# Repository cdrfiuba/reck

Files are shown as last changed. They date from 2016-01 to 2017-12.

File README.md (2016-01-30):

# reck
R.E.C.K

Robot Eyes Caterpillar Kinect

Robot autónomo con capacidad para filmar, seguir un objeto, entre otras caracteristicas.

Caracteristicas generales: altura entre 1 y 1,5 metros; sistema de desplazamiento con orugas; cuenta con una Raspberry Pi; "cabeza" formada por una Kinect; "cuerpo" acoplado a la estructura de un gabinete, lugar donde se van a colocar las placas de conexión; la estructura va a estar conectada a través de caños; la proteccion de las placas va a ser con placa de acrílilco.

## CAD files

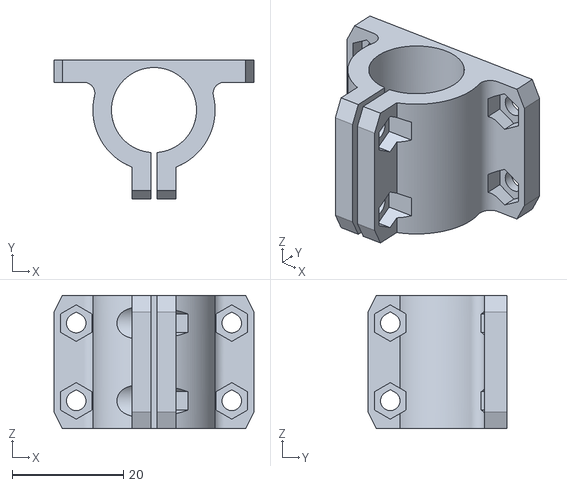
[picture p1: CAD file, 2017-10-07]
3dmodels/lm8uu_holder_v2.stl
36.0 x 25.0 x 24.0

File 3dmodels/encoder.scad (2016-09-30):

$fn=250;
module motor(){
cylinder(h=2.5,d=10);
cylinder(h=6,d=2);
translate([0,0,-20])cylinder(h=20,d=28);

translate([23/2.0,-2,0])cube([0.5,4,7]);
translate([-23/2.0-0.5,-2,0])cube([0.5,4,7]);
}

module encoder(N){
  L = 360/(2*N);
  difference(){
    union(){
      translate([0,0,2.6])cylinder(h=1.2  , d=22);
      translate([0,0,2.6])cylinder(h=3.4, d= 5);
    }
    translate([0,0,2.5])
    difference() {
      union(){
        for(i=[0:(N-1)])
        rotate([0,0,i*360/N])
        polyhedron( 
          points = [ [0, 0, 0], [15, 0, 0], [15*cos(L),15*sin(L),0],[0, 0, 2], [15, 0, 2], [15*cos(L),15*sin(L),2]], 
          faces = [ [0, 1, 4, 3], [1,2,5,4],[2,0,3,5],[0,2,1],[3,4,5] ], 
          convexity = 10);
      }
      cylinder(h=4.5, d=6);
    }
    translate([0,0,2])cylinder(h=5, d=2.6);
  }
}

module pcb() {
  difference(){
    translate([0,0,4])cylinder(h=1.8, d=28);
    translate([23/2.0-0.15,-2.15,5])cube([0.8,4.3,7]);
    translate([-23/2.0-0.65,-2.15,5])cube([0.8,4.3,7]);
    translate([0,0,2])cylinder(h=5, d=6);
    rotate([0,0,45])translate([3.5,-2.15,3.5]) cube([7.3,4.3,3]);
    rotate([0,0,135])translate([3.5,-2.15,3.5]) cube([7.3,4.3,3]);
    
  }
}

//motor();
encoder(3);
//pcb();

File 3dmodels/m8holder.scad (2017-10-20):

import("lm8uu_holder_v2.stl");
translate([-4,2.5,0])cube([8,2.5,2]);

difference(){
  cylinder(h=24,r=8);
  cylinder(h=24.1,r=4.15,$fn=60);
  translate([0.5,0,0]) rotate([0,0,180])cube([1,20,24]);
}

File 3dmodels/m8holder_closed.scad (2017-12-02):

import("lm8uu_holder_v2.stl");

difference() {
  cylinder(h=1,d=18);
  cylinder(h=1,d=9);
  translate([-0.5,-20,0]) cube([1,20,2]);
}

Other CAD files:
3dmodels/plantilla_madera.scad
3dmodels/sprockets.scad
3dmodels/sprockets_reck.scad

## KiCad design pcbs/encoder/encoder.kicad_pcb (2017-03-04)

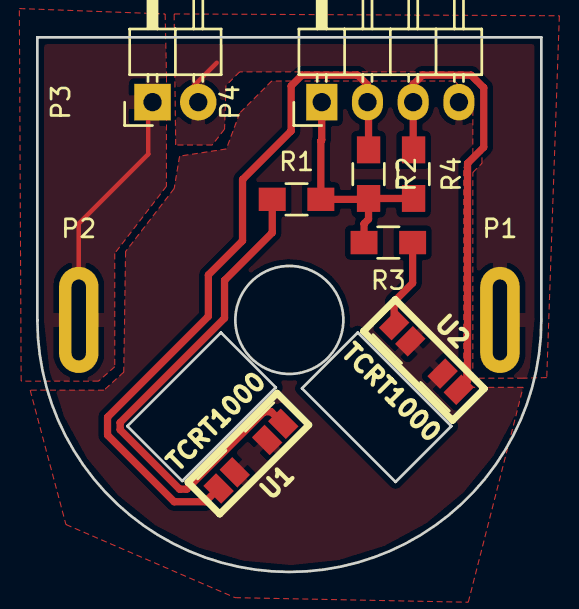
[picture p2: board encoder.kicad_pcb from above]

Board: 2 copper layers, 28.0 x 29.7 mm, 10 parts (0 on the bottom side), 8 nets.

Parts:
P1: M1; SolderWirePad_single_2-5mmDrill
P2: M2; SolderWirePad_single_2-5mmDrill
P3: Motor; Pin_Header_Angled_1x02
P4: CONN_01X04; Pin_Header_Angled_1x04
R1, R2: 180; R_0805_HandSoldering
R3, R4: 33k; R_0805_HandSoldering
U1: TCRT1000; tcrt1000-smd
U2: TCRT1000

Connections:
+5V: P4.1, R1.2, R2.2, R3.2, R4.2
/S1: P4.2, R2.1, U1.4
/S2: P4.3, R4.1, U2.4
GND: P4.4, U1.2, U1.3, U2.2, U2.3
unnamed: P1.1, P3.2
unnamed: P2.1, P3.1
unnamed: R1.1, U1.1
unnamed: R3.1, U2.1

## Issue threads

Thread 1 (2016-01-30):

Actualizar readme

yagui, 2016-01-30:
poner una descripción del robot

julimarasco, 2016-01-30:
Verificar si eso es lo que va en el Readme.
No tengo idea que poner ahí.

yagui, 2016-02-02:
Esta bien, era una primera descripción del robot la cual está bien

Closed 2016-02-02.

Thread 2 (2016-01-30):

subir foto

yagui, 2016-01-30:
edita la wiki y agrega la foto

julimarasco, 2016-01-30:
No se como hacerlo!  :-1:
Lo google pero no lo entendí.

yagui, 2016-02-02:
descargue el repo de la wiki, agregué la foto al repo en mi compu, subi los cambios, y luego edite de vuelta la wiki

Closed 2016-02-02.

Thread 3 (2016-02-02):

armar mail de introduccion

yagui, 2016-02-02:
Armar un mail contando la idea general para atraer gente que quiera trabajar en el proyecto.
Comentar que por un lado hay que armar la estructura, así que hay trabajo para mecánicos y no mecánicos que les guste la parte estructural.
Hay que armar toda la electrónica, desde sensores, control de motores, distribución de energía, etc.
Estética, interacción con el humano. Y sobre software/firmware, estaremos trabajando con ROS a sugerencia de Ernesto.

yagui, 2016-02-02:
@ernestmc

Closed 2016-02-03.

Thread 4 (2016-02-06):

Comprar tarjeta micro SD para rPI 2

sebasgm, 2016-02-06:
Para poder empezar a utilizar la Raspberry PI 2 necesitamos una micro SD

Monty1991, 2016-02-06:
Tengo una Sandisk de 32 gb sin usar, sirve?

sebasgm, 2016-02-06:
Sirve hasta que podamos comprar una. Si querés traela y ni bien tengamos una nueva te la podés llevar.

Monty1991, 2016-02-06:
Dale. ¿Cuándo empiezan a reunirse (en el club, supongo)?

yagui, 2016-07-22:
Juli ya compró la SD

Closed 2016-07-22.

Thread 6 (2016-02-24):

Interfaz humana

ernestmc, 2016-02-24:
Ideas para darle al robot una interfaz más natural y amistosa con las personas, que simule rasgos humanos. Algo similar a [ésta](http://spectrum.ieee.org/automaton/robotics/industrial-robots/sawyer-rethink-robotics-new-robot).

* Usar una tablet Android para dibujar la cara. Se podría usar la propia cámara de la tablet para hacer reconocimiento facial del interlocutor y de esta forma interpretar ciertas expresiones y emociones. Mediante [Rosjava](http://wiki.ros.org/rosjava) y un enlace wifi se puede conectar con el resto del sistema del robot.

* Usando [Jasper](https://jasperproject.github.io/) se puede hacer reconocimiento de voz para interpretar comandos. Existen módulos para usar en español.

* Usar algún sintetizador de voz para emitir respuestas vocales (investigar cuál, si se puede usar en español).

Monty1991, 2016-02-25:
En cuanto a sintetizadores de voz, el único que conozco es el del Vocaloid (Yamaha). Una versión adaptada (o la misma) se usó para Kibo, el robot asistente japonés para la ISS. Lo que no se es si se puede usar en tiempo real. La otra es trabajar con un bando de fonemas pregrabados (El núcleo del Vocaloid).

ernestmc, 2016-03-03:
Fuentes de inspiración: http://robotic.media.mit.edu/
Ver por ejemplo el [Dragonbot](http://robotic.media.mit.edu/portfolio/dragonbot/)
Tienen una plataforma que corre en Android para la interface robot humano (HRI): https://github.com/personal-robots/SAR-opal-base
Y un tracker de caras en Android: https://github.com/personal-robots/android-clm-tracker

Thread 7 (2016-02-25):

Sistema de tracción

ernestmc, 2016-02-25:
Me parece que el sistema de orugas va a ser difícil de implementar, especialmente el armado de las orugas. Propongo hacer un sistema con tracción en las cuatro ruedas: dos de un lado y dos del otro:

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

Se pueden usar piñones, coronas y cadenas de bicicleta o moto. Por ejemplo este kit de moto que se consigue en [Mercadolibre](http://articulo.mercadolibre.com.ar/MLA-607233544-kit-transmision-motos-110-corona-cadena-pinon-sti-motos-_JM):

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

yagui, 2016-07-23:
la cinta o cadena debería tener 2 metros de perímetro aproximadamente, para un robot de 75-80 cm de largo

yagui, 2016-08-07:
Con la idea de Ernest, decidimos armar algo como lo que proponen acá
http://www.instructables.com/id/How-to-make-custom-and-strong-tank-tracks-for-very/

Las cadenas cuestan alrededor de 100 pesos cada una (ML), y hay una herramienta para cortar cadenas y volver a unirlas, con lo cual se pueden comprar varias cadenas para armar todas las orugas. La herramienta cuesta 150 pesos pero quizás se consiga mas barata en ML.
Una cadena de 2 metros necesitaría de 1 cadena y media comercial. Es decir, comprando 3 hacemos 2 para el robot.
Los piñones cuestan también entre 50 y 100 pesos (ML). Hay que comprar del mismo paso que la cadena.

*Queda definir si usamos 2 o 3 cadenas para cada oruga (4 o 6 en total, es decir 8 o 12 metros).
*Queda definir las maderas que usaríamos para armar la oruga.
*Queda definir cuantos piñones usamos por oruga.

yagui, 2016-08-13:
Vamos a comprar 6 cadenas
http://articulo.mercadolibre.com.ar/MLA-623311125-cadena-para-bicicleta-kmc-hv410-marron-_JM
y uno de estos para armar las cadenas
http://articulo.mercadolibre.com.ar/MLA-628260843-corta-cadena-basico-marca-bike-hand-326a-_JM

Los eslabones son de 1/2 pulgada, y cada soporte va separado cada 2 pulgadas.

En total habrá 40 maderas por oruga, dando un total de 80 pulgadas o sea, 2,03 metros de orugas.

80 tablitas de 5 x 30 x 200 cm (o de 8 mm)

yagui, 2017-12-02:
compramos las cadenas.

Closed 2017-12-02.

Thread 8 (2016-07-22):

Definir motores

yagui, 2016-07-22:
Definir los motores a utilizar para poder comenzar a armar la estructura.

Motores de 12 V (para la batería de Gel)
40 - 50 rpm

yagui, 2016-08-07:
Se compraron 2 motores SP6-50 de AP&S

http://www.apys.com.ar/productos/motorreductores_sp6.html

tienen el eje extendido para armar un encoder

Closed 2016-08-07.

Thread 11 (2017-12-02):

compras para sistema de tracción

yagui, 2017-12-02:
Comprar:

diametro 3 mm
200 tornillos de 1,5 cm  (para bujes a madera)
100 tornillo de 1 cm (para cerrar los bujes)
16 de 4 cm   (engranaje sin tapa)
8 de 5,5 cm   (engranaje con tapa)
24 de 1,2 cm   (para fijar eje)

400 tuercas de 3 mm

6 resortes de mas de 8mm de diametro. entre 8.5 y 10.  10 cm de largo.
Comprar primero algunas variantes para probar.

sierra de copa de 2 pulgadas (50 mm)

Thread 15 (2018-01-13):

imprimir piezas para orugas

yagui, 2018-01-13:
12  soporte para M8  (2 por suspension)
12 soporte para ruleman cerrado (para que choque el resorte) (2 por suspension)
24 soporte para ruleman abierto (4 por suspension)

yagui, 2018-01-13:
Hay impresos
5 soporte para M8
4 soportes para ruleman cerrados
5 soportes para ruleman abiertos

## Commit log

2016-08-13 Plantilla para las maderas
    Plantilla para poder marcar los agujeros de las maderas para las orugas
    [plantilla_madera.scad]
2016-09-30 encoder a utilizar en el motor
    [encoder.scad]
2016-09-30 PCB del encoder
    [encoder.kicad_pcb, encoder.sch]
2017-03-04 muevo la plantilla a la carpeta 3d y actualizo
    [plantilla_madera.scad]
2017-10-07 agregamos una pieza para sostener las barras M8
    [lm8uu_holder_v2.stl, m8holder.scad]
2017-10-20 correccion en el diamentro de la barra
    [m8holder.scad]
2017-10-20 agrego los engranajes
    [sprockets.scad, sprockets_reck.scad]
2017-10-21 actualizacion de engranajes para reck
    [sprockets_reck.scad]
2017-10-23 Agregue las dos tapas de engranajes
    [sprockets_reck.scad]
2017-10-27 agrego *.stl al gitignore
2017-10-29 actualizacion de engranajes para reck con tapa abierta y cerrada
    [sprockets_reck.scad]
2017-11-11 agrego el esquema de todos los engranajes de una oruga
    [sprockets_reck.scad]
2017-11-11 corregimos medidas para canio de 1 1/2
    [sprockets_reck.scad]
2017-11-21 cambios hechos a partir de la primera impresion
    [plantilla_madera.scad, sprockets.scad, sprockets_reck.scad]
2017-12-02 Agregamos un tope al soporte de buje
    [m8holder_closed.scad]
